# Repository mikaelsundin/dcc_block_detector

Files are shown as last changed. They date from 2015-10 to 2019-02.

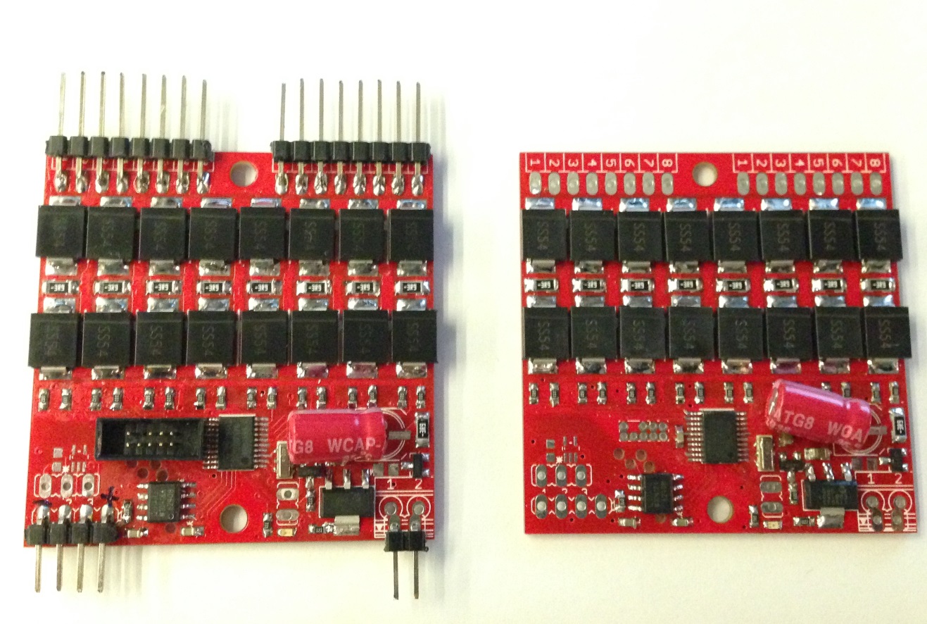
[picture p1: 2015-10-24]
doc/board.jpg

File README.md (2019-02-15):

# dcc_block_detector
A dcc block detector based on STM32F030 and measure current over diode-drop

#This detector is usefull both for N-Scale and H0-scale. 
A SMC diode of 5A can handle alot of current.
For N-scale its possible to use regular pin header at IO1, IO2 (max 3A).
For HO scale i recommend screw terminal to handle more current.

#Note
Another board with a MCU is needed to translate from uart to other protocols.

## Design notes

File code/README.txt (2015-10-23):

Tool used:
 * Emblocks 2.3 

Emblocks Segger Jlink GDB settings:

J-Link GDB Server Arguments:
 "-select USB -device STM32F030F4 -if SWD -speed 1000 -noir"
Reset Command(s):
 "monitor reset"

After Connection:
  "monitor flash download = 1
   monitor flash breakpoints = 1

   load
   monitor reset
   break main
   continue"

Note:
Remember to change linker script to match CPU flash/ram size if changed.

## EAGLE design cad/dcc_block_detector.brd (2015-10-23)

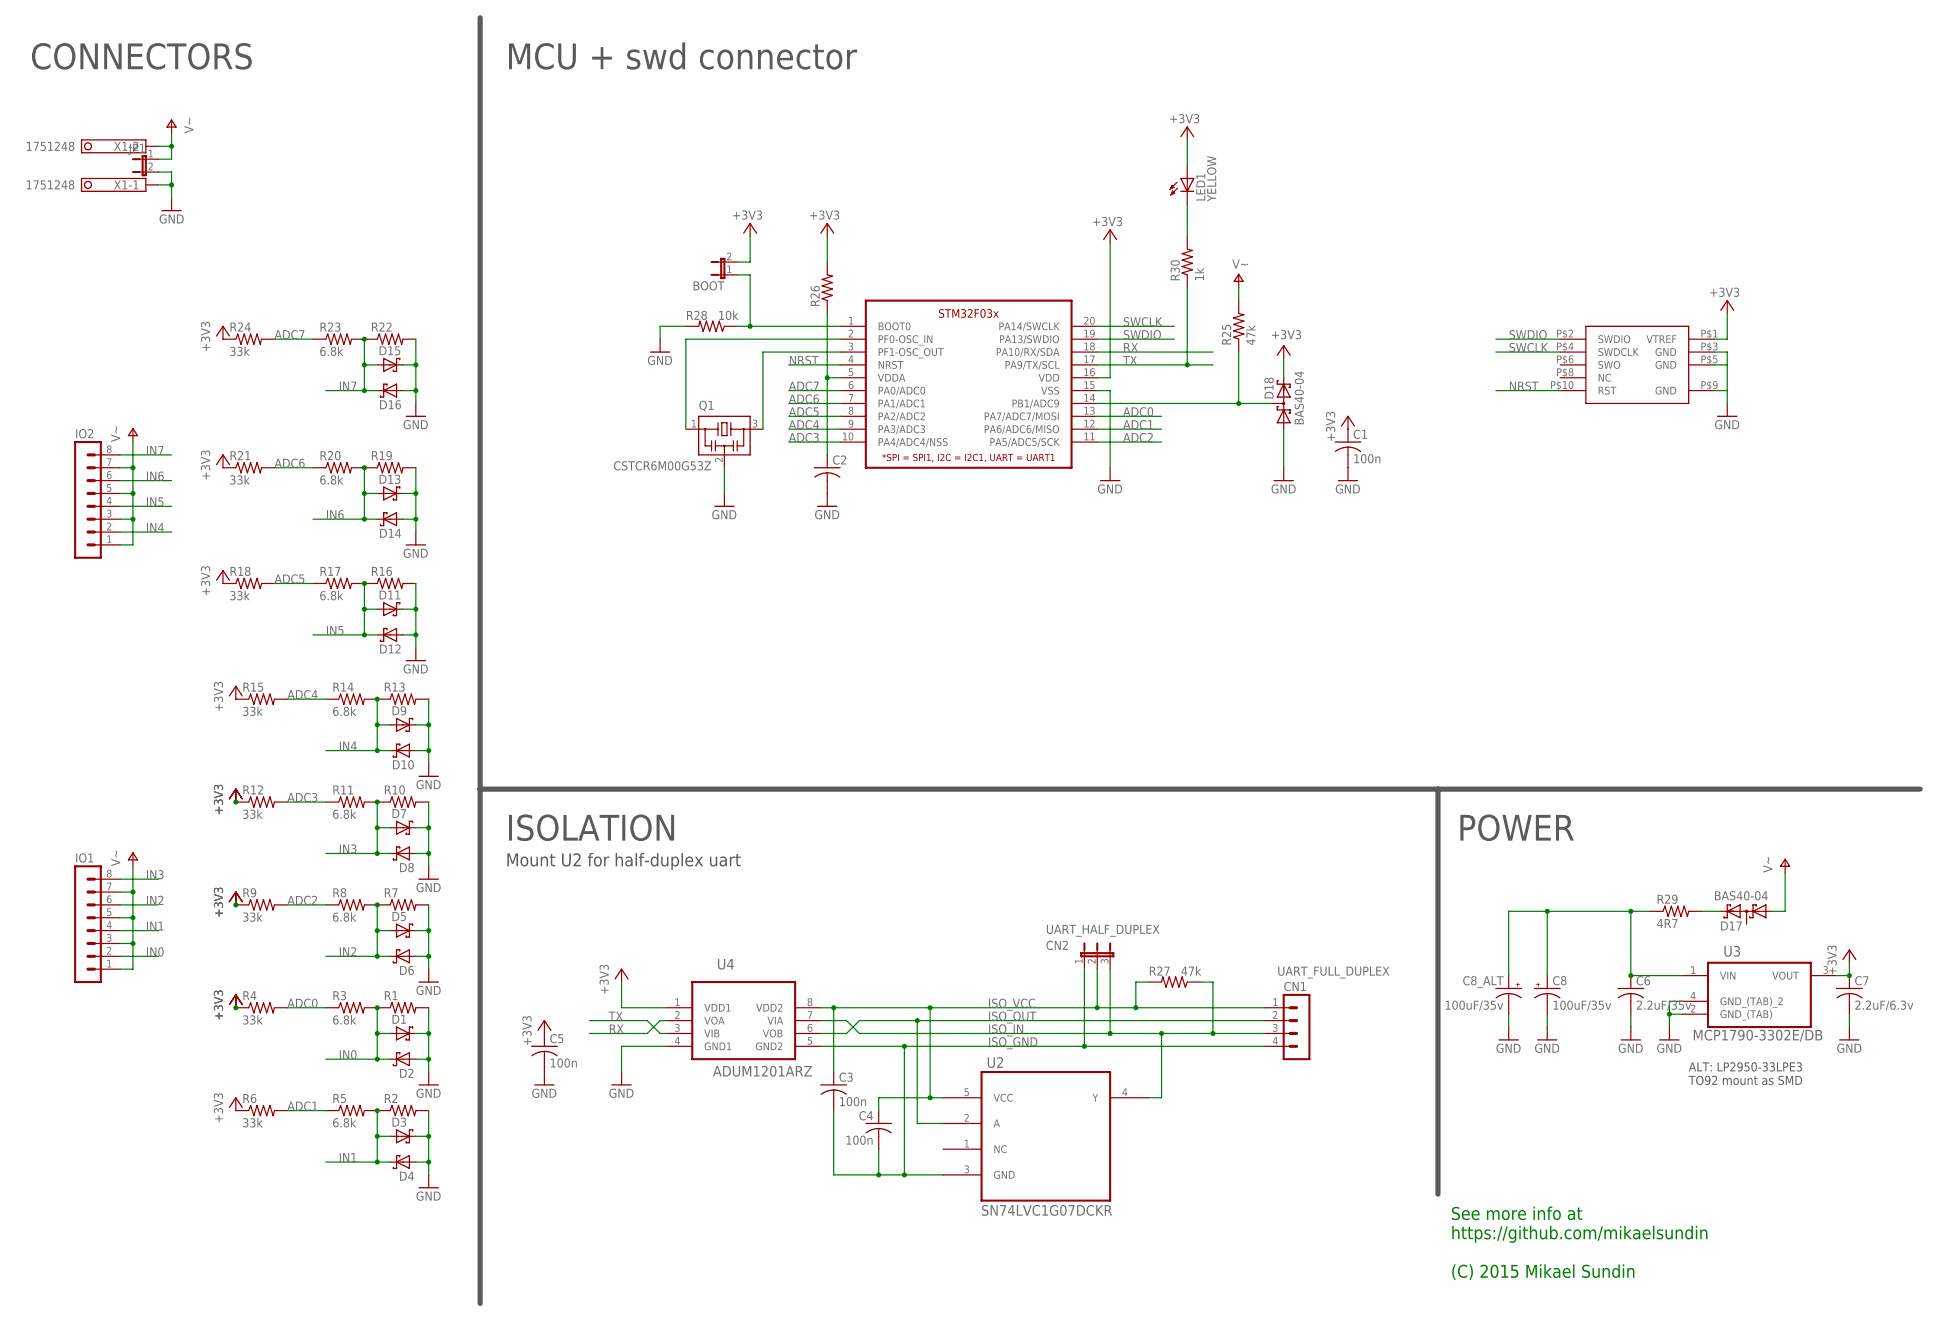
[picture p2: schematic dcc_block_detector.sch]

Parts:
BOOT: JP1E; JP1
C1, C3, C4, C5: 100n; C0603
C2: C-USC0603; C0603
C6: 2.2uF/35v; C0805
C7: 2.2uF/6.3v; C0805
C8: 100uF/35v; UD-6,3X7,7_NICHICON
C8_ALT: 100uF/35v; E2,5-6
CN1: UART_FULL_DUPLEX; MA04-1
CN2: UART_HALF_DUPLEX; JP2
D1, D2, D3, D4, D5, D6, D7, D8, D9, D10, D11, D12, D13, D14, D15, D16: SCHOTTKY-DIODESMC; SMC
D17, D18: BAS40-04; SOT23
IO1, IO2: MA08-1W
JP1: JP1E; JP1
LED1: YELLOW; CHIPLED_0603
Q1: CSTCR6M00G53Z; CSTER12M
R1, R2, R7, R10, R13, R16, R19, R22: R-US_R1206; R1206
R3, R5, R8, R11, R14, R17, R20, R23: 6.8k; R0603
R4, R6, R9, R12, R15, R18, R21, R24: 33k; R0603
R25, R27: 47k; R0603
R26: R-US_R0603; R0603
R28: 10k; R0603
R29: 4R7; R1206
R30: 1k; R0603
U2: SN74LVC1G07DCKR; SOT65P210X110-5N
U3: MCP1790-3302E/DB; SOT230P700X180-4N
U4: ADUM1201ARZ; SOIC127P600X175-8N
U$1: STM32F03X_TSSOP20
U$2: SWD; ARM_SWD_2X5
X1: 1751248

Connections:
+3V3: BOOT.2, C1.1, C5.1, C7.1, D18.2 (C2), LED1.A, R4.1, R6.1, R9.1, R12.1, R15.1, R18.1, R21.1, R24.1, R26.2, U3.3 (VOUT), U4.1 (VDD1), U$1.16 (VDD), U$2.P$1 (VTREF)
ADC0: R3.1, R4.2, U$1.13 (PA7/ADC7/MOSI)
ADC1: R5.1, R6.2, U$1.12 (PA6/ADC6/MISO)
ADC2: R8.1, R9.2, U$1.11 (PA5/ADC5/SCK)
ADC3: R11.1, R12.2, U$1.10 (PA4/ADC4/NSS)
ADC4: R14.1, R15.2, U$1.9 (PA3/ADC3)
ADC5: R17.1, R18.2, U$1.8 (PA2/ADC2)
ADC6: R20.1, R21.2, U$1.7 (PA1/ADC1)
ADC7: R23.1, R24.2, U$1.6 (PA0/ADC0)
GND: C1.2, C2.2, C5.2, C6.2, C7.2, C8.-, C8_ALT.-, D1.C, D2.A, D3.C, D4.A, D5.C, D6.A, D7.C, D8.A, D9.C, D10.A, D11.C, D12.A, D13.C, D14.A, D15.C, D16.A, D18.1 (A1), JP1.2, Q1.2, R1.2, R2.2, R7.2, R10.2, R13.2, R16.2, R19.2, R22.2, R28.2, U3.2 (GND_(TAB)), U3.4 (GND_(TAB)_2), U4.4 (GND1), U$1.15 (VSS), U$2.P$3 (GND), U$2.P$5 (GND), U$2.P$9 (GND), X1.1
IN0: D1.A, D2.C, IO1.2, R1.1, R3.2
IN1: D3.A, D4.C, IO1.4, R2.1, R5.2
IN2: D5.A, D6.C, IO1.6, R7.1, R8.2
IN3: D7.A, D8.C, IO1.8, R10.1, R11.2
IN4: D9.A, D10.C, IO2.2, R13.1, R14.2
IN5: D11.A, D12.C, IO2.4, R16.1, R17.2
IN6: D13.A, D14.C, IO2.6, R19.1, R20.2
IN7: D15.A, D16.C, IO2.8, R22.1, R23.2
ISO_GND: C3.2, C4.2, CN1.4, CN2.1, U2.3 (GND), U4.5 (GND2)
ISO_IN: CN1.3, CN2.3, R27.1, U2.4 (Y), U4.7 (VIA)
ISO_OUT: CN1.2, U2.2 (A), U4.6 (VOB)
ISO_VCC: C3.1, C4.1, CN1.1, CN2.2, R27.2, U2.5 (VCC), U4.8 (VDD2)
unnamed: D18.3 (C1A2), R25.1, U$1.14 (PB1/ADC9)
unnamed: C2.1, R26.1, U$1.5 (VDDA)
unnamed: D17.2 (C2), R29.2
unnamed: Q1.1, U$1.2 (PF0-OSC_IN)
unnamed: Q1.3, U$1.3 (PF1-OSC_OUT)
unnamed: BOOT.1, R28.1, U$1.1 (BOOT0)
unnamed: C6.1, C8.+, C8_ALT.+, R29.1, U3.1 (VIN)
unnamed: LED1.C, R30.2
NRST: U$1.4 (NRST), U$2.P$10 (RST)
RX: U4.2 (VOA), U$1.18 (PA10/RX/SDA)
SWCLK: U$1.20 (PA14/SWCLK), U$2.P$4 (SWDCLK)
SWDIO: U$1.19 (PA13/SWDIO), U$2.P$2 (SWDIO)
TX: R30.1, U4.3 (VIB), U$1.17 (PA9/TX/SCL)
V+: D17.1 (A1), IO1.1, IO1.3, IO1.5, IO1.7, IO2.1, IO2.3, IO2.5, IO2.7, JP1.1, R25.2, X1.2

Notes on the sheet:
CONNECTORS
MCU + swd connector
ISOLATION
POWER
See more info at https://github.com/mikaelsundin (C) 2015 Mikael Sundin
Mount U2 for half-duplex uart
ALT: LP2950-33LPE3 TO92 mount as SMD

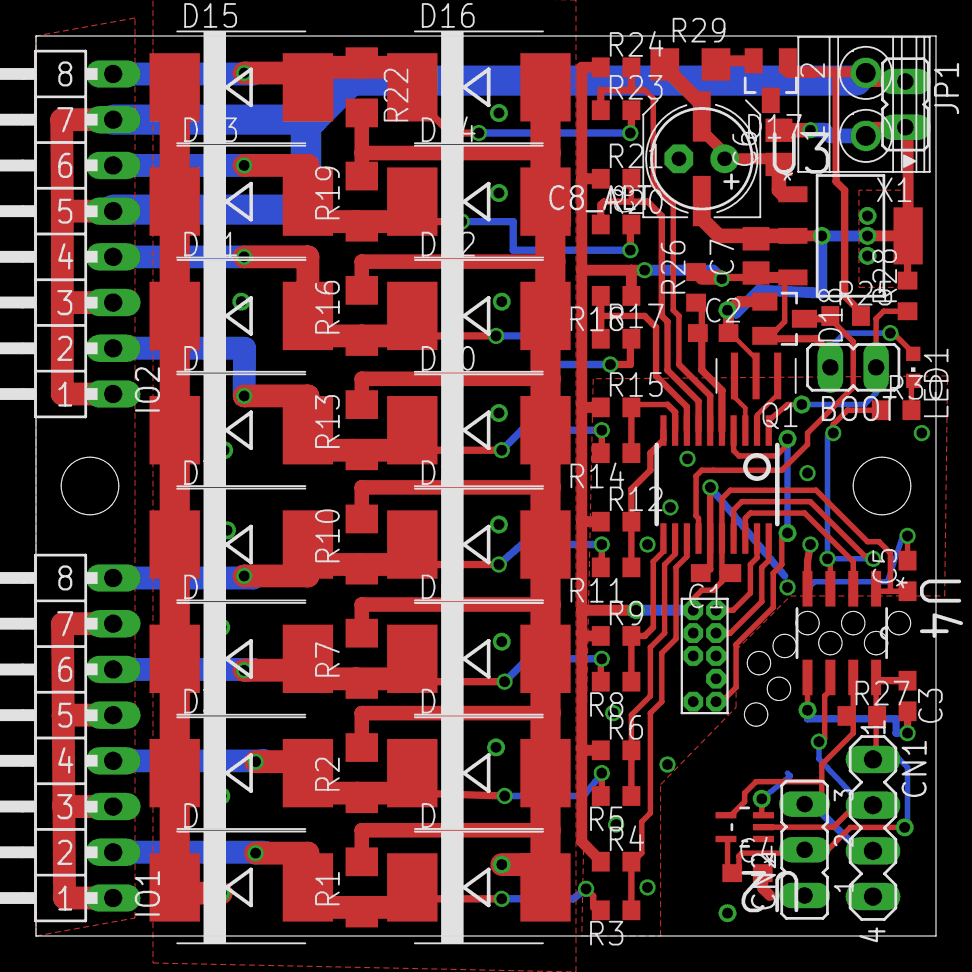
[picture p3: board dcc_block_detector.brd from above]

Board: 2 copper layers, 50.0 x 50.0 mm, 71 parts (0 on the bottom side), 36 nets.

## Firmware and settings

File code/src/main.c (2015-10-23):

/*********************************************************************
**
**                           Main.c
**
**
**********************************************************************/
/*********************************************************************
   Last committed:     2015-10-07
   Last changed by:    Mikael Sundin
   Last changed date:  2015-10-23
   ID:                 main.c
   TODO:               Clean-up and split into different files.

**********************************************************************/
#include "stm32f0xx_conf.h"
#include <stdint.h>
#include <stdbool.h>
#include "uart.h"
#include "array_fn.h"

#define SOFTWARE_NAME       "DCC Block detector"
#define SOFTWARE_VERSION    "1.0"


//hard-coded threshold for now, seems to work good and detect over 5mA.
#define DETECTOR_THRESHOLD  4

//number of ADC channels
#define ADC_COUNT           8

//number of samples to collect from every channel
#define ADC_NBR_OF_SAMPLES   8

//private functions
static void init_hal(void);
static void nvic_init(void);
static void init_dcc_pin(void);
static void init_adc(void);

const char *build_str = "#" SOFTWARE_NAME " Version: " SOFTWARE_VERSION " " __DATE__ " " __TIME__;
volatile uint16_t adc_data[ADC_COUNT*ADC_NBR_OF_SAMPLES];


void init_adc(void)
{
    int i;
    ADC_InitTypeDef ADC_InitStructure;
    DMA_InitTypeDef DMA_InitStructure;
    GPIO_InitTypeDef GPIO_InitStructure;

    ADC_StructInit(&ADC_InitStructure);
    GPIO_StructInit(&GPIO_InitStructure);

    ADC_DeInit(ADC1);
    DMA_DeInit(DMA1_Channel1);

    DMA_InitStructure.DMA_PeripheralBaseAddr = (uint32_t)&ADC1->DR;
    DMA_InitStructure.DMA_MemoryBaseAddr = (uint32_t)&adc_data[0];
    DMA_InitStructure.DMA_DIR = DMA_DIR_PeripheralSRC;
    DMA_InitStructure.DMA_BufferSize = (ADC_COUNT*ADC_NBR_OF_SAMPLES);
    DMA_InitStructure.DMA_PeripheralInc = DMA_PeripheralInc_Disable;
    DMA_InitStructure.DMA_MemoryInc = DMA_MemoryInc_Enable;
    DMA_InitStructure.DMA_PeripheralDataSize = DMA_PeripheralDataSize_HalfWord;
    DMA_InitStructure.DMA_MemoryDataSize = DMA_MemoryDataSize_HalfWord;
    DMA_InitStructure.DMA_Mode = DMA_Mode_Circular;
    DMA_InitStructure.DMA_Priority = DMA_Priority_High;
    DMA_InitStructure.DMA_M2M = DMA_M2M_Disable;
    DMA_Init(DMA1_Channel1, &DMA_InitStructure);
    DMA_Cmd(DMA1_Channel1, ENABLE);

    ADC_DMARequestModeConfig(ADC1, ADC_DMAMode_Circular);

    /* Configure the ADC1 in continous mode withe a resolutuion equal to 12 bits  */
    ADC_InitStructure.ADC_Resolution = ADC_Resolution_12b;
    ADC_InitStructure.ADC_ContinuousConvMode = DISABLE;
    ADC_InitStructure.ADC_ExternalTrigConvEdge = ADC_ExternalTrigConvEdge_None;
    ADC_InitStructure.ADC_DataAlign = ADC_DataAlign_Right;
    ADC_InitStructure.ADC_ScanDirection = ADC_ScanDirection_Upward;
    ADC_Init(ADC1, &ADC_InitStructure);

    //configure PA0-PA7
    GPIO_InitStructure.GPIO_Mode = GPIO_Mode_AN;
    GPIO_InitStructure.GPIO_PuPd = GPIO_PuPd_NOPULL ;
    for(i=0;i<ADC_COUNT;i++){
        ADC_ChannelConfig(ADC1, 1<<i , ADC_SampleTime_7_5Cycles);
        GPIO_InitStructure.GPIO_Pin = 1<<i;
        GPIO_Init(GPIOA, &GPIO_InitStructure);
    }

    ADC_GetCalibrationFactor(ADC1);
    ADC_Cmd(ADC1, ENABLE);
    while(!ADC_GetFlagStatus(ADC1, ADC_FLAG_ADEN)){};

    //turn on DMA after calibration, else we got a extra DMA request
    ADC_DMACmd(ADC1, ENABLE);
}

void init_dcc_pin(void){
    GPIO_InitTypeDef GPIO_InitStructure;
    EXTI_InitTypeDef EXTI_InitStructure;

    //PB1 used to sync to dcc signal.
    GPIO_StructInit(&GPIO_InitStructure);
    GPIO_InitStructure.GPIO_Pin = GPIO_Pin_1;
    GPIO_InitStructure.GPIO_Mode = GPIO_Mode_IN;
    GPIO_InitStructure.GPIO_PuPd = GPIO_PuPd_NOPULL;
    GPIO_Init(GPIOB, &GPIO_InitStructure);

    EXTI_StructInit(&EXTI_InitStructure);
    EXTI_InitStructure.EXTI_Line = EXTI_Line1;
    EXTI_InitStructure.EXTI_Mode = EXTI_Mode_Interrupt;
    EXTI_InitStructure.EXTI_Trigger = EXTI_Trigger_Rising_Falling;
    EXTI_InitStructure.EXTI_LineCmd = ENABLE;
    EXTI_Init(&EXTI_InitStructure);

    SYSCFG_EXTILineConfig(EXTI_PortSourceGPIOB, EXTI_PinSource1);
}

//start a conversion on DCC trigger
void EXTI0_1_IRQHandler(void){
    if(EXTI_GetITStatus(EXTI_Line1) != RESET){
        EXTI_ClearITPendingBit(EXTI_Line1);
        ADC_StartOfConversion(ADC1);
    }
}

void nvic_init(void){
    NVIC_InitTypeDef NVIC_InitStructure;

    NVIC_InitStructure.NVIC_IRQChannel = EXTI0_1_IRQn;
    NVIC_InitStructure.NVIC_IRQChannelPriority = 0x01; //0-3
    NVIC_InitStructure.NVIC_IRQChannelCmd = ENABLE;
    NVIC_Init(&NVIC_InitStructure);
}


void init_hal(void){
    RCC_APB2PeriphClockCmd(RCC_APB2Periph_SYSCFG | RCC_APB2Periph_USART1 | RCC_APB2Periph_ADC1, ENABLE);
    RCC_AHBPeriphClockCmd(RCC_AHBPeriph_DMA1 | RCC_AHBPeriph_GPIOA | RCC_AHBPeriph_GPIOB, ENABLE);

    init_adc();
    init_dcc_pin();
    init_usart();
}



volatile bool update_flag=false;

void SysTick_Handler(void)  {
    static uint32_t cnt=0;

    if(cnt++ >= 250){
        cnt = 0;
        update_flag = true;
    }
}

//seems that we need ~5mA to detect anything on the track
int main(void)
{
    int i;
    uint8_t current_state=0;
    uint8_t last_state=0;
    int32_t tmp_diff;
    uint16_t adc_min[ADC_COUNT];
    uint16_t adc_max[ADC_COUNT];
    int32_t adc_diff[ADC_COUNT];

    SystemInit();
    nvic_init();
    init_hal();
    SysTick_Config(SystemCoreClock / 1000); //1ms interrupt

    //print software version
    print_ln((char*)build_str);

    while(1)
    {
        current_state = 0;
        for(i=0;i<ADC_COUNT;i++){
            adc_min[i] = get_array16_min((uint16_t*)&adc_data[i], ADC_COUNT, ADC_NBR_OF_SAMPLES);
            adc_max[i] = get_array16_max((uint16_t*)&adc_data[i], ADC_COUNT, ADC_NBR_OF_SAMPLES);

            //lowpass iir filter on difference.
            tmp_diff = (adc_max[i] - adc_min[i]);
            adc_diff[i] = (adc_diff[i]*31 + tmp_diff)/32;

            //convert array to bitmask
            if(adc_diff[i] >= DETECTOR_THRESHOLD){
                current_state |= 1<<i;
            }

        }

        //periodically check current state
        if(update_flag){
            update_flag = 0;
            if(current_state != last_state){
                last_state = current_state;
                print_hex_ln(current_state);
            }
        }
    }
}

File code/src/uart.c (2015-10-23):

#include "stm32f0xx_conf.h"

#include "uart.h"

/**
 * Try to read one byte from usart
 * @return non zero on receive
 */
char read_usart(void){
    if(USART_GetFlagStatus(USART1, USART_FLAG_RXNE) == SET){
        return USART_ReceiveData(USART1);
    }else{
        return 0;
    }



}

/**
 * @brief send one char over uart
 * @param ch char to send
 */
void write_usart(char ch){
    while (USART_GetFlagStatus(USART1, USART_FLAG_TXE) == RESET){};
    USART_SendData(USART1, ch);
}

/**
 * @brief initialize uart
 */
void init_usart(void){
    GPIO_InitTypeDef GPIO_InitStructure;
    USART_InitTypeDef USART_InitStructure;

    USART_InitStructure.USART_BaudRate = 9600;
    USART_InitStructure.USART_WordLength = USART_WordLength_8b;
    USART_InitStructure.USART_StopBits = USART_StopBits_1;
    USART_InitStructure.USART_Parity = USART_Parity_No;
    USART_InitStructure.USART_HardwareFlowControl = USART_HardwareFlowControl_None;
    USART_InitStructure.USART_Mode = USART_Mode_Rx | USART_Mode_Tx;

    USART_Init (USART1, &USART_InitStructure);
    USART_Cmd (USART1, ENABLE);

    //configure alternative function for PA9, PA10 to UART1
    GPIO_PinAFConfig(GPIOA, GPIO_PinSource9, GPIO_AF_1);
    GPIO_PinAFConfig(GPIOA, GPIO_PinSource10, GPIO_AF_1);

    //TX pin
    GPIO_InitStructure.GPIO_Pin = GPIO_Pin_9 | GPIO_Pin_10;
    GPIO_InitStructure.GPIO_Speed  = GPIO_Speed_2MHz;
    GPIO_InitStructure.GPIO_Mode = GPIO_Mode_AF;
    GPIO_InitStructure.GPIO_PuPd = GPIO_PuPd_UP;
    GPIO_Init(GPIOA, &GPIO_InitStructure);
}


/**
 * @brief simple function to send a uint8_t as hex with an appended newline.
 */
void print_hex_ln(uint8_t val){
    char nibble2hex[] = {'0', '1','2','3','4','5','6','7','8','9','A', 'B', 'C', 'D', 'E', 'F'};

    write_usart( nibble2hex[val>>4 & 0x0F]);
    write_usart( nibble2hex[val>>0 & 0x0F]);
    write_usart('\n');
}

/**
 * @brief simple function to send a string with an appended newline.
 */
void print_ln(char* str){
    while(*str != 0){
        write_usart(*str++);
    }
    write_usart('\n');
}

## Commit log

2015-10-08 Added cad files and code that perform some basic tasks.
    [dcc_block_detector.brd, dcc_block_detector.sch]
2015-10-23 Code working as expected. First working release.
    [dcc_block_detector.brd, dcc_block_detector.sch]
2015-10-24 Lower clock speed to save power. Added a image of a soldered board.
